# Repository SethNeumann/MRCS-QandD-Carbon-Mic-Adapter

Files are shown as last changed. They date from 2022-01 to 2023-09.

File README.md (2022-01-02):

# MRCS-QandD-Carbon-Mic-Adapter

## License: Creative Commons Attribution-NonCommercial-ShareAlike

I designed this adapter after working with Lee Nicholas on the phone system for the Utah, Colorado and Western. Lee has a carbon mic in a metal enclosure on a boom
over his CTC machine for the Dispatcher's use.  Lee had also been using my Active Telephone Speech Network (ATSN) for use with a computer headset, powered speaker and a 
footswitch. At one time he wanted to use the ATSN with the carbon mic, but ATSN supports dynamics and Electrets, but ATSN doesn't supply enough current for a carbon mic.
This adapter takes filtered 12V (or any voltage up to 24V with changes to the dropping resistor) and powers a carbon mic. The mic is in paralled with 600:600 isolation
transformer (in series with a 1uF blocking cap) and provides line level audio out.  This audio can feed an ATSN or any line to power amplifier, numerous powered speakers 
and and small amplifier boards are avaialable which will work well with the MRCS-QandD-Carbon-Mic-Adapter.

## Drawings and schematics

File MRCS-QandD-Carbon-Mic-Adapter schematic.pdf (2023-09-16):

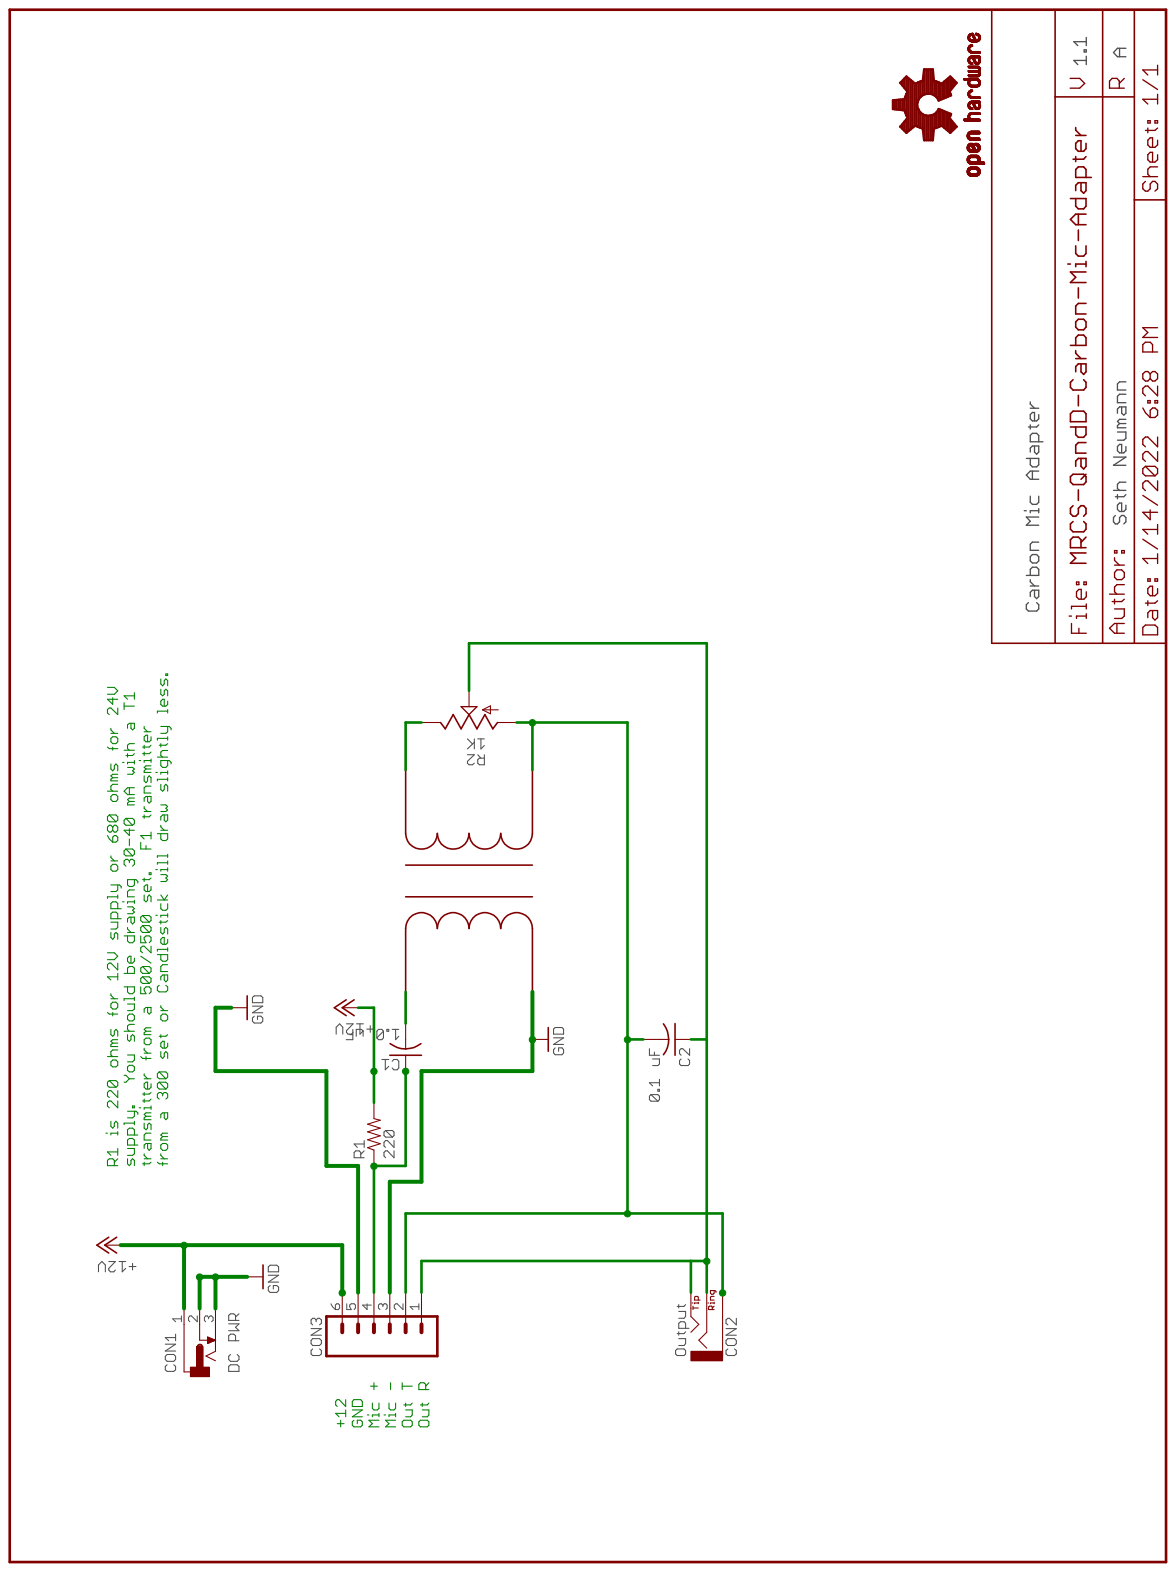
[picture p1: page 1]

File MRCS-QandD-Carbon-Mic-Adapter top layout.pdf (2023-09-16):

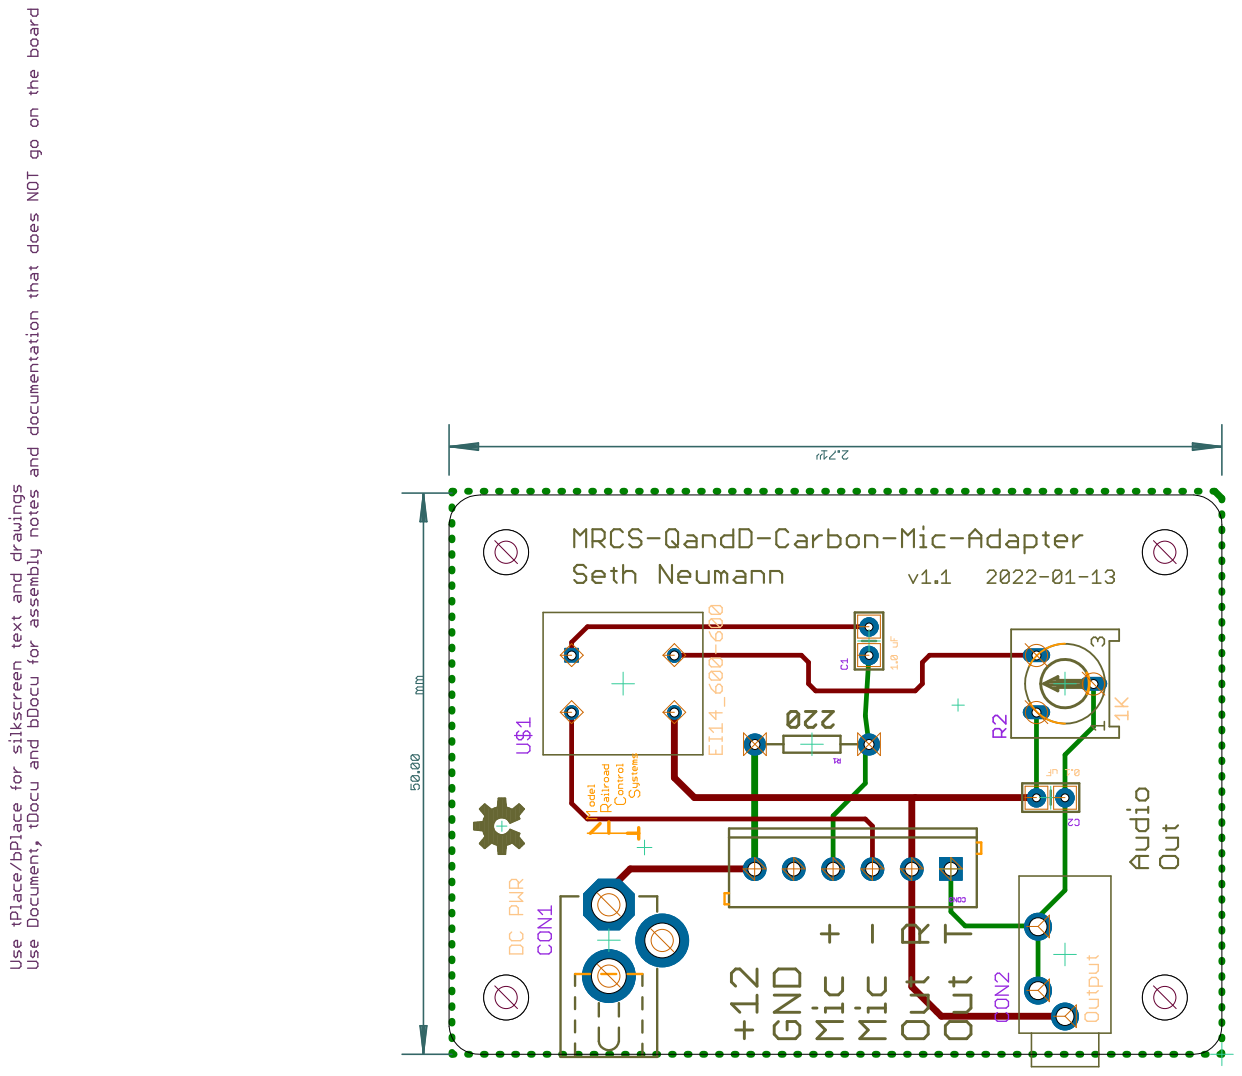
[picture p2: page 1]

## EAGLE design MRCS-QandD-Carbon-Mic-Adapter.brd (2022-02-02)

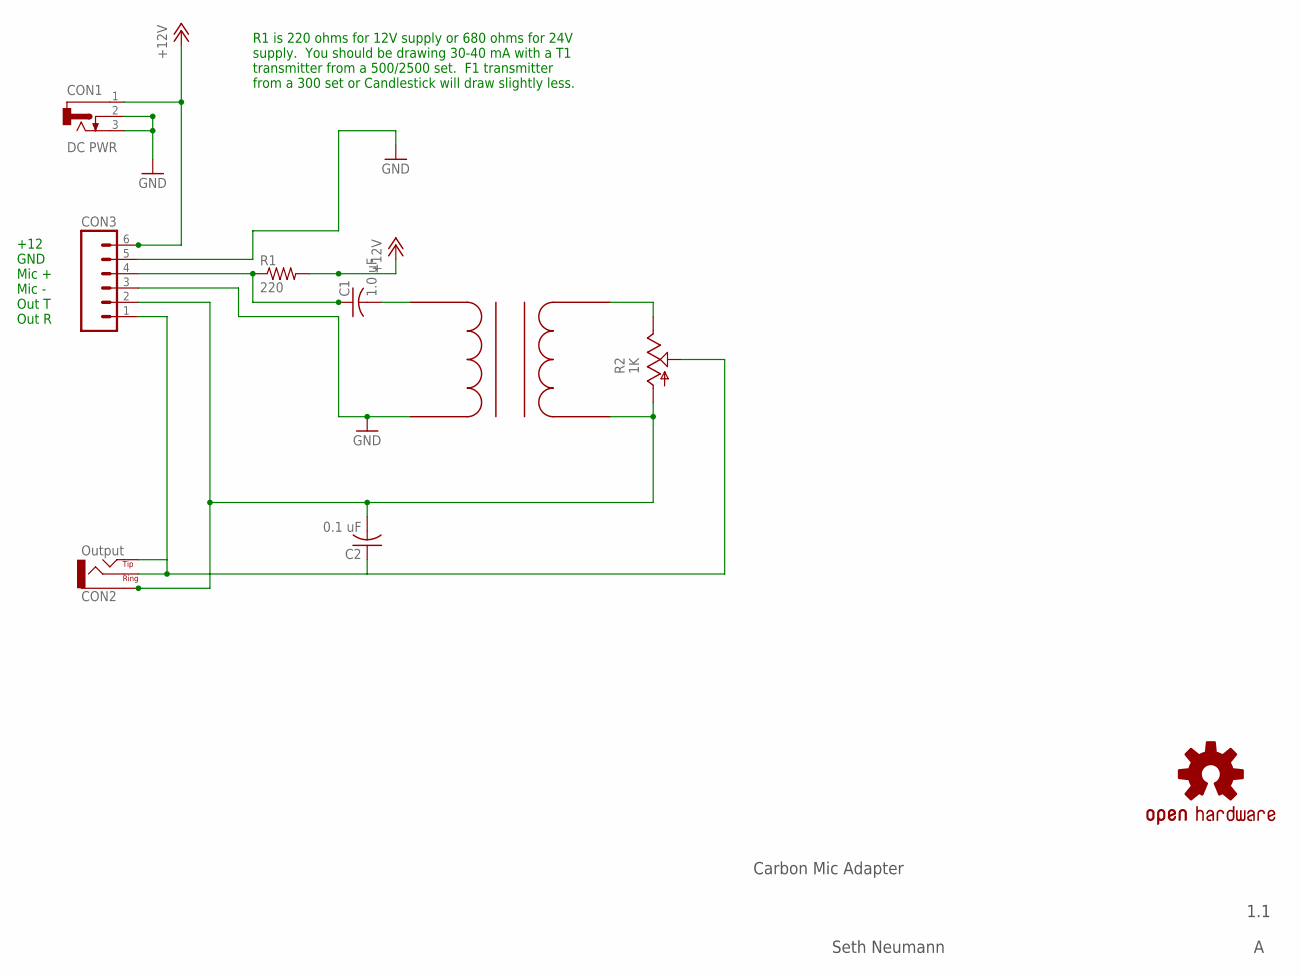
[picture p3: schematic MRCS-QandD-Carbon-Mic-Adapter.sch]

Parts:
C1: 1.0 uF; C-PTH-0.100
C2: 0.1 uF; C-PTH-0.100
CON1: DC PWR; DCJ0202
CON2: Output; AUDIO-JACK-3.5MM_STEREO
CON3: CONNECTOR-M063.5MM-6; SCREWTERMINAL-3.5MM-6
OSHW1: DOC-OSHW-LOGO-M; OSHW-LOGO-M
R1: 220; AXIAL-0.4-RES
R2: 1K; RS3
U$1: EI14_600-600; XFMR580X500

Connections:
+12V: CON1.1, CON3.6, R1.P$2 (2)
GND: CON1.2, CON1.3, CON3.3, CON3.5, U$1.PBOTTOM
MIC+: C1.1, CON3.4, R1.P$1 (1)
unnamed: R2.E, U$1.STOP
unnamed: C1.2, U$1.PTOP
unnamed: C2.1, CON2.RING, CON2.TIP, CON3.1, R2.S
OUTT: C2.2, CON2.GND (SLEEVE), CON3.2, R2.A, U$1.SBOTTOM

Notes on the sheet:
Carbon Mic Adapter
1.1
Seth Neumann
+12 GND Mic + Mic - Out T Out R
R1 is 220 ohms for 12V supply or 680 ohms for 24V supply. You should be drawing 30-40 mA with a T1 transmitter from a 500/2500 set. F1 transmitter from a 300 set or Candlestick will draw slightly less.

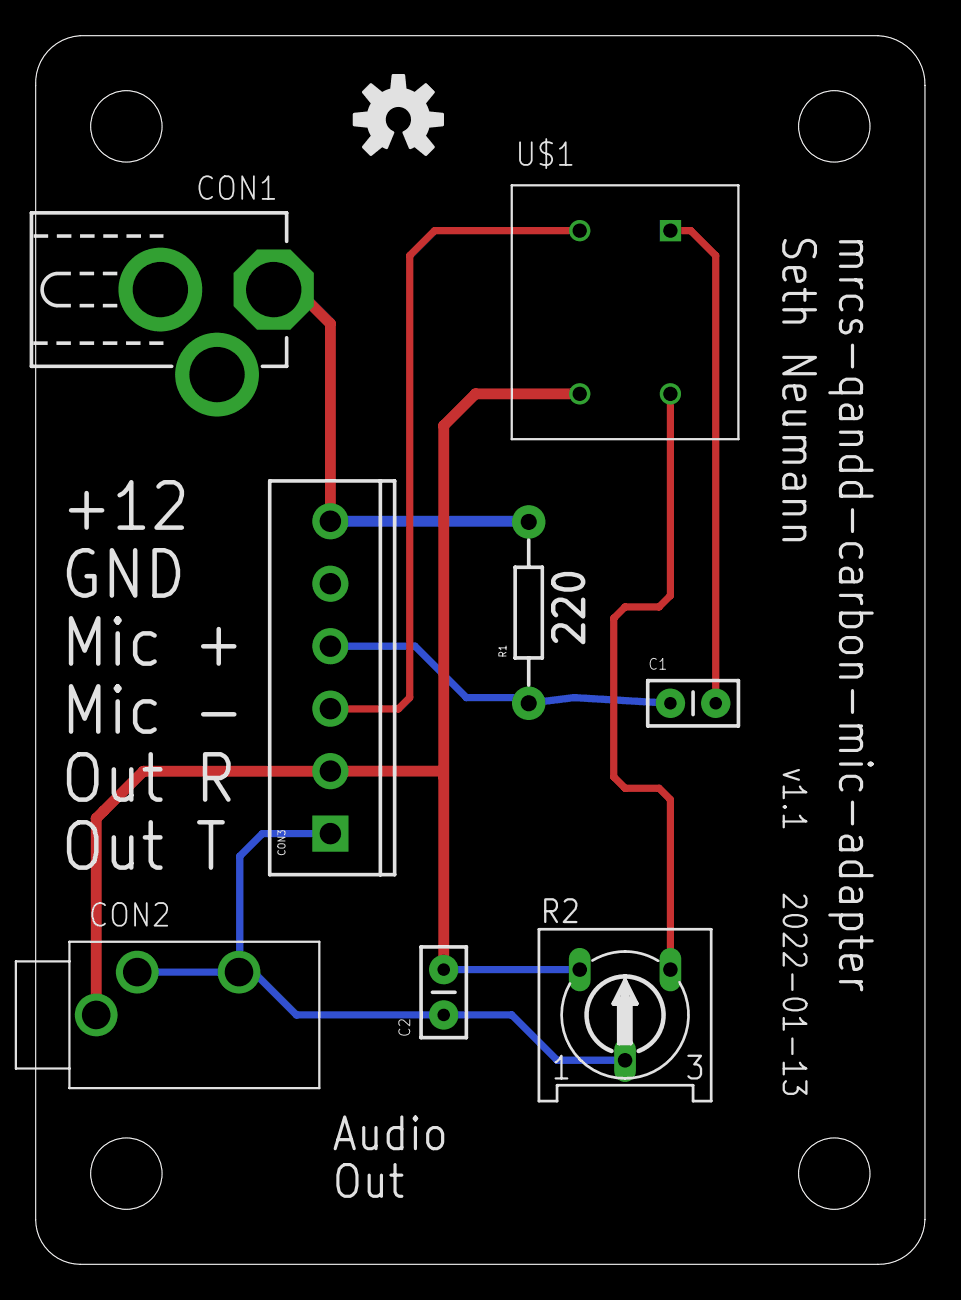
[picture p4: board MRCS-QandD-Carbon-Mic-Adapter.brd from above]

Board: 2 copper layers, 49.8 x 68.8 mm, 12 parts (0 on the bottom side), 7 nets.

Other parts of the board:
U$2: BOARD-DINRAIL-2.7IN-5CM
U$3: MRCSLOGOTOP
U$4: CA-PROP65WARNING

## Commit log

2022-01-02 changed names of templates
    changed names of templates
    [MRCS-QandD-Carbon-Mic-Adapter.brd, MRCS-QandD-Carbon-Mic-Adapter.sch]
2022-01-03 Initial design sent to PCB Fab on 1/2/22
    First pass board, easier to make the PCB than fool with a bread board.
    [MRCS-QandD-Carbon-Mic-Adapter.brd, MRCS-QandD-Carbon-Mic-Adapter.sch]
2022-02-02 Version 1.1 fixed input ground, general cleanup
    Version 1.1 fixed input ground, general cleanup
    [MRCS-QandD-Carbon-Mic-Adapter.brd, MRCS-QandD-Carbon-Mic-Adapter.sch]
2022-02-08 after 2nd revision
    fixed floating ground, cleaned up labels
2023-09-16 pdfs of Schematic and layout
    cleaning up documentation

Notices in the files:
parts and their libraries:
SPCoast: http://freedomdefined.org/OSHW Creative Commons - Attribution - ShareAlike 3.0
